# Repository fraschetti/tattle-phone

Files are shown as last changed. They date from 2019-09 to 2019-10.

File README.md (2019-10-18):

# Tattle Phone
A RaspberryPi enabled tattle phone capable of recording voice messages, converting them to text, & making everything available to you via [Slack](https://slack.com) or [Pipedream](https://pipedream.com). Originally inspired by this [No Fair! - This American Life](https://www.thisamericanlife.org/672/no-fair/prologue-2) segment.

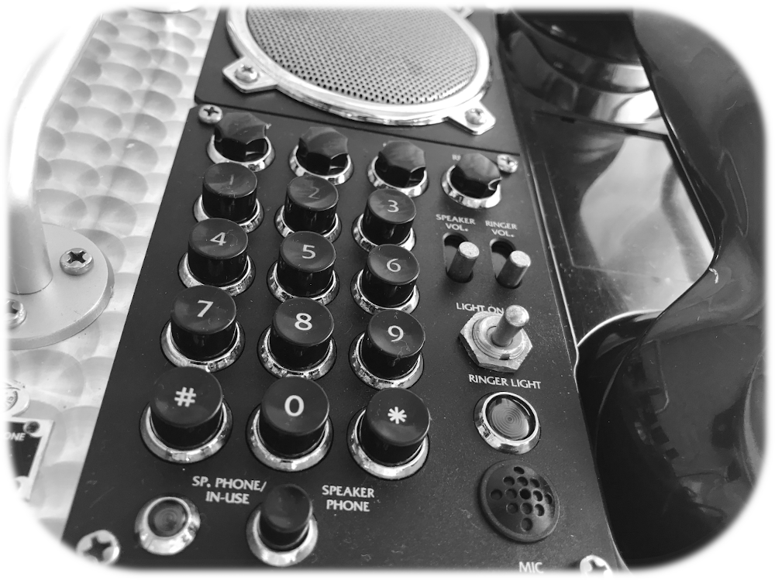
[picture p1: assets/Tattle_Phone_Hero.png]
Tattle phone


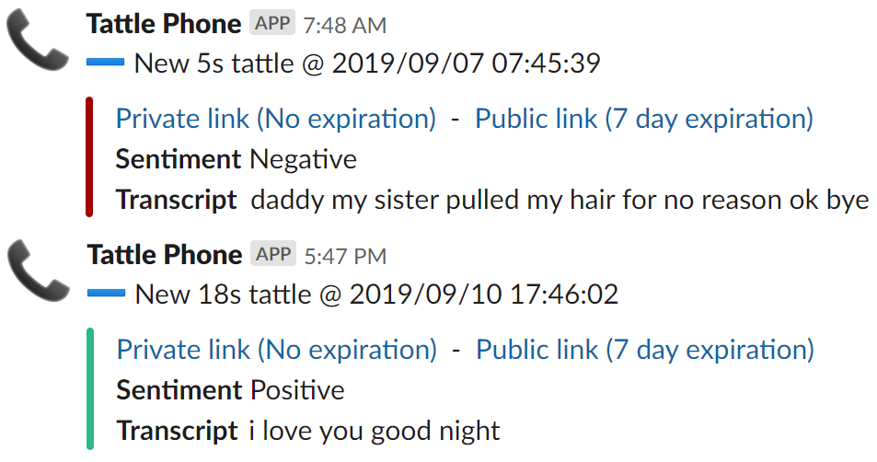
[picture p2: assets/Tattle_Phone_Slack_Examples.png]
Slack examples


**What's actually happens:**
- Picking up the telephone handset triggers the Python logic to start recording
- After the handset is placed back on the phone (or a maximum recording duration is reached), the recording is uploaded to Amazon S3
- The recording is then optionally passed through Amazon Transcribe (voice --> text) and Amazon Comprehend (text --> sentiment) for further analysis
  - NOTE: Both Transcribe and Comprehend have free usage plans that should be more than sufficient for this project
- After all processing is complete, a Slack or Pipedream message is posted with a link to the recording and transcript and sentiment information if enabled.

## BOM (Bill of Materials)
- Raspberry Pi Zero W or any other WiFi enabled Raspberry Pi
- Telephone with an analog receiver (two wires for the speaker & two wires for the microphone)
  - Telephones with the keypad in the handset are likely going to be a pain to use as the cord doesn't contain the microphone wires you'd want to leverage on the Pi you'll be mounting into the telephone base)
- Rasperry Pi compatible USB audio adapter
- [Optional] Status LED
- [Optional] 1k resistor for the status LED (only required if using a status LED)
- [Optional] PCB Screw Terminal Block (useful when prototyping)
- [Optional] 3.5mm 1/8 male headphone jack to terminal block adapter  (useful when prototyping)
- [Optional] Electret microphone (useful for prototyping)

#### Microphone protoype
- Search for "3.5mm audio terminal block" on eBay or AliExpress
- This prototype provided better quality recordings than my teleophone receiver implementation
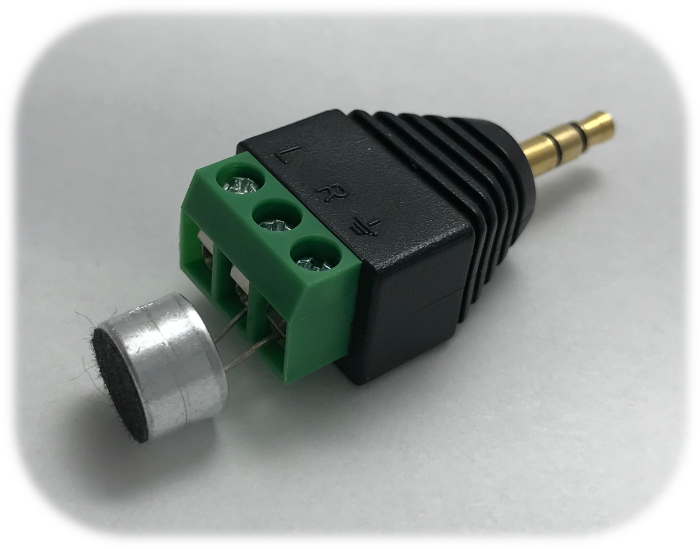
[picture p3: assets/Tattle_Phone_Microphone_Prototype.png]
Microphone prototype


#### USB audio adapter
- Search for "USB Sound Card Adapter" on eBay or AliExpress
- This model comes with a rather annoying red status LED which illuminates whenever the adapter is in use
  - It was literally a two minute task to slice open the case with a utility knife, desolder the surface mount LED, and put the case back together with a bit of cyanoacrylate ("super glue") 
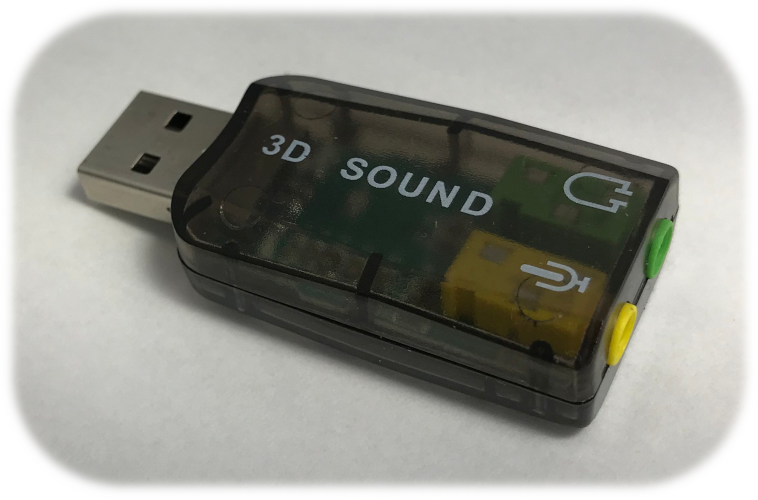
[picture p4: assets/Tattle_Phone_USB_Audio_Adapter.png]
USB Audio Adapter


#### PCB screw terminal block
- Search for "2.54mm PCB Screw Terminal Block" on eBay or AliExpress
- A six pole terminal block will satisfy the requirements of this project with room for future enhancements
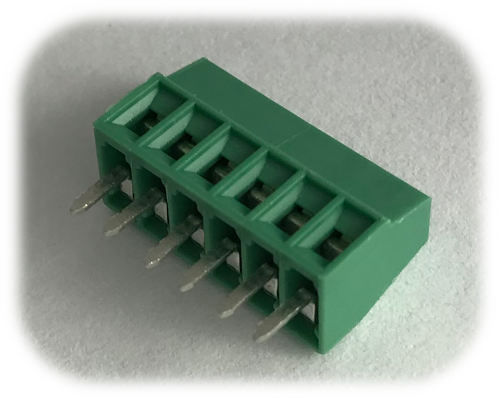
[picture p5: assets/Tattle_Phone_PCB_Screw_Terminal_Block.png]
PCB Screw Terminal Block


## Wiring diagram
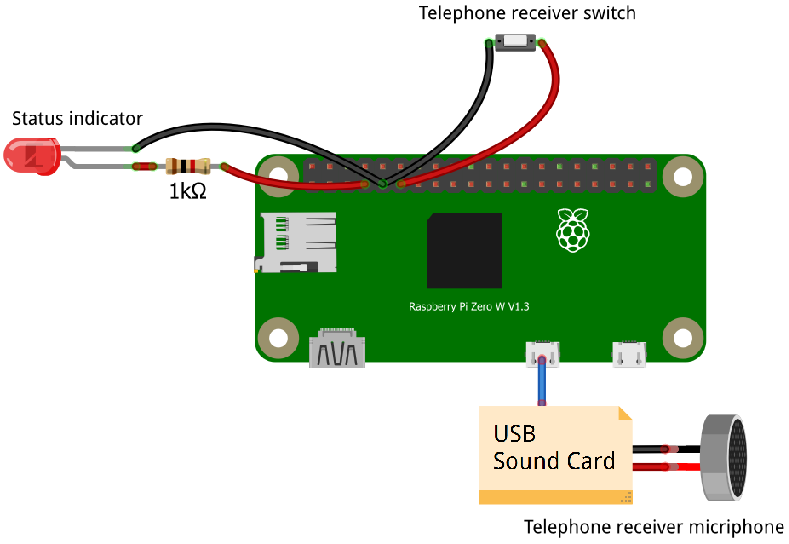
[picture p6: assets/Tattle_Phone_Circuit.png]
Wiring diagram


## Software
- Install the prequisites
  ```
  sudo apt-get install libportaudio0 libportaudio2 libportaudiocpp0 portaudio19-dev
  sudo python -m pip install pyaudio PyYAML boto3 slacker
  ```
- Populate your local yaml [configuration file](config.yaml)

- Populate your AWS credential and configuration files
  - /home/pi/.aws/credentials
    ```
    [default]
    aws_access_key_id = <aws_access_key_id>
    aws_secret_access_key = <aws_secret_access_key>
    ```  
  - /home/pi/.aws/config
    - Best practice would be to use the same region as your config.yaml file
    ```
    [default]
    region = <preferred_aws_region>
    ```
- Install the tattle-phone service - process adapted from [here](https://www.raspberrypi.org/forums/viewtopic.php?t=197513#p1247341)
  - Commands and scripts assume Pi is running [Raspian](https://www.raspberrypi.org/downloads/) and the tattle-phone project contents have been deployed at **/home/pi/tattle-phone**. To use a different path, simply modify the steps below, the [tattle.service](tattle.service) file and .sh files accordingly.
    ```
    sudo cp tattle.service /etc/systemd/system/tattle.service
    sudo chmod 644 /etc/systemd/system/tattle.service
    sudo systemctl daemon-reload
    sudo systemctl enable tattle.service
    sudo systemctl start tattle.service
    ```
## Power savings
Unfortunately none of the Raspberry Pi boards have any power saving modes and the best we can do is disable components we don't need. Assuming you're leveraging the on-board WiFI, you can still disable the Bluetooth hardware, HDMI output, and on-board status LEDs.

- A great resource for disabling the onboard WiFI and/or Bluetooth can be found [here](https://blog.sleeplessbeastie.eu/2018/12/31/how-to-disable-onboard-wifi-and-bluetooth-on-raspberry-pi-3/)
- To disable the on-board HDMI (and with a bit of work - the on-board LEDs), you might consider leveraging [tattle_power_savings.sh](tattle_power_savings.sh)
     - The command below assume the tattle-phone project have been deployed at **/home/pi/tattle-phone**
     ```
    sudo chmod 775 /home/pi/tattle-phone/tattle_power_savings.sh
    sudo sed -i -e '$i /home/pi/tattle-phone/tattle_power_savings.sh\n' /etc/rc.local
    ```
## My implementation
I was putting the finishing touches on the software when a last minute business trip popped up. I wanted to give my oldest daughter a fun way to contact me while I was away so I cobbled together a working tattle phone for her to use. It was a success!

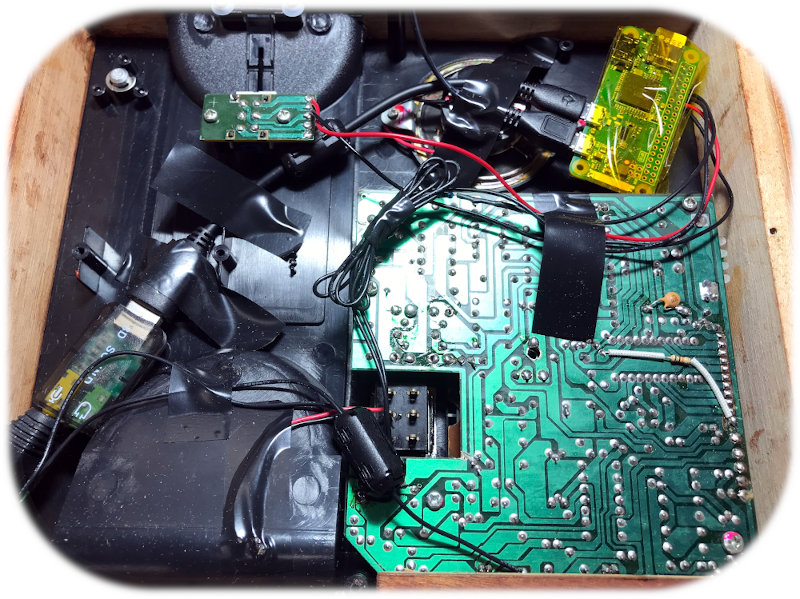
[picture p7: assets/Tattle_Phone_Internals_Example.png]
Internals Example

- It was fairly easy to use a multimeter to determine which wires I could leverage to detect the phone haved been lifted off the base. The other unncessary wires from the switch were trimmed to reduce clutter
- Luckily the phone's board was only a single layer and utilized through-hole components and that made quick work of leveraging the phone's existing components
  - It was easy enough to spot which pins were handling the microphone inputs and the existing on-board status LED for the phone.
  - I soldered in a handful of wires, cut the traces to isolate the microphone and LED from the rest of the board, and we were good to go.

## What would a v2 look like?
The Pi offers a lot of convienance but it is wildly overpowered for this project and even with the above *Power savings*, is going to waste a lot of energy * money. If I were to revisit this project, I'd likely start over using an ESP32 or similar microcontroller with built-in WiFi, processing power, and deep-sleep power saving modes (similar to what I used on my [ESP8266-TempSensor](https://github.com/fraschetti/ESP8266-TempSensor) project).

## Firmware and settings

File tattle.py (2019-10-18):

#!/usr/bin/python

import os
import sys
import logging
import logging.handlers as handlers
import yaml
import json
import RPi.GPIO as GPIO
import pyaudio
import time
import threading
import boto3
import botocore
import requests
from sound_recorder import SoundRecorder
from datetime import datetime
from tempfile import mkstemp
from slacker import IncomingWebhook


file_log_format = '%(asctime)s  %(levelname)s  %(message)s'
console_log_format = file_log_format

logger = logging.getLogger()
logger.setLevel(logging.INFO)

file_handler = handlers.TimedRotatingFileHandler('tattle.log', when='midnight')
file_handler.setFormatter(logging.Formatter(file_log_format))
logger.addHandler(file_handler)

console_handler = logging.StreamHandler()
console_handler.setFormatter(logging.Formatter(console_log_format))
logger.addHandler(console_handler)

cfg = None
handset_pin = None
led_pin = None
need_receiver_reset = False #Requires the reciver to be 'hung up' before the next recording

run_test = False #Run once and exit

def main():
        global cfg
        global handset_pin
        global led_pin
        global need_receiver_reset 

	p = pyaudio.PyAudio()
	device_count = p.get_device_count()
	
	logger.info("")
	logger.info("")
	logger.info("-=Tattle App=-")
	logger.info("")
	logger.info("Loading config...")

        led_pin = None

        try:
            with open("config.yaml", 'r') as ymlfile:
                cfg = yaml.load(ymlfile, Loader=yaml.FullLoader)
                logger.info("\n\n" + yaml.dump(cfg, Dumper=yaml.Dumper))

                handset_pin = cfg["handset"]["handset_pin"]
                led_pin = cfg["recording"]["led_pin"]

                if not handset_pin:
                    logger.error("Handset pin not configured")
                    return
        except Exception:
            logger.exception("Config read error")
            return

	logger.info("- Audio devices (" + str(device_count) + ") -")
	for i in range(device_count):
	    device_info = p.get_device_info_by_index(i)
	    print_device_info(device_info)	
		
	logger.info("")
	logger.info("- Default recording device -")
	mic_device_info = p.get_default_input_device_info()
	print_device_info(mic_device_info)

        # Pin Setup:
        GPIO.setwarnings(False)
        GPIO.setmode(GPIO.BCM) # Broadcom pin-numbering scheme
        GPIO.setup(handset_pin, GPIO.IN, pull_up_down=GPIO.PUD_UP) # Button pin set as input w/ pull-up

        if led_pin:
            GPIO.setup(led_pin, GPIO.OUT) # LED pin set as output
            GPIO.output(led_pin, GPIO.LOW)

        logged_waiting_msg = False

        if is_phone_off_hook():
            logger.warn("Receiver initial state is off the hook. Preventing false recording on start")
            need_receiver_reset = True

        while True:
            try:
                if not logged_waiting_msg:
	            logger.info("")
	            logger.info("-------------------------------------")
	            logger.info("Waiting for tattle...")
	            logger.info("-------------------------------------")
	            logger.info("")
                    logged_waiting_msg = True

                if is_phone_off_hook() or run_test:
                    #Need to wait until the reciver is hung up again before a new recording can occur
                    if not need_receiver_reset:
                        logged_waiting_msg = False
                        capture_audio()

                    if run_test:
                        need_receiver_reset = True #Prevent multiple recording during the test cycle
                else:
                    need_receiver_reset = False
            except Exception:
                logger.exception("Main loop error")

            time.sleep(0.5)


def is_phone_off_hook():
    return GPIO.input(handset_pin)


##TODO CHRIS Encode to MP3 if it makes sense (currently doesn't)
##TODO CHRIS move from path aws credentials to yaml settings
##TODO CHRIS flash LED on startup
##TODO CHRIS send slack msssage on service start/stop ?
##RODO CHRIS send initial slack msg immediately and updates as post-processing occurs
##TODO CHRIS https://www.instructables.com/id/Disable-the-Built-in-Sound-Card-of-Raspberry-Pi/
##TODO CHRIS https://aws.amazon.com/blogs/database/indexing-metadata-in-amazon-elasticsearch-service-using-aws-lambda-and-python/
##TODO CHRIS Doc disabling built-in audio - https://www.raspberrypi.org/forums/viewtopic.php?t=37873
def capture_audio():
    rec_tmp_file_path = None

    try:
        global need_receiver_reset 

        base_name = "tattle_" + time.strftime('%Y%m%d_%H%M%S')

        #recording 
        rec_filename = base_name + ".wav"
        rec_tmp_fd, rec_tmp_file_path = mkstemp()
        os.close(rec_tmp_fd)

        tattle_props = {
                'id' : base_name,
                'rec_filename' : rec_filename,
                'timestamp' : datetime.now().strftime("%Y/%m/%d %H:%M:%S"),
                'rec_url' : None,
                'rec_public_url' : None,
                'rec_duration' : None,
                'transcript_url' : None,
                'transcript' : None,
                'sentiment' : None,
                'key_phrases' : [],
            }

        with SoundRecorder(rec_tmp_file_path) as rec:
    	    logger.info("Starting recording - " + rec_filename)
    	    rec.start_recording()
            adjust_recording_led(True)

            recording_min_secs = int(cfg["recording"]["min_secs"])
            recording_max_secs = int(cfg["recording"]["max_secs"])

            min_record_end = None
            max_record_end = None

            if recording_min_secs and recording_min_secs > 0:
                min_record_end = time.time() + recording_min_secs
            if recording_max_secs and recording_max_secs > 0:
                max_record_end = time.time() + recording_max_secs

            continue_recording = True

            while continue_recording:
    	        time.sleep(0.25)

                min_met = min_record_end == None or time.time() >= min_record_end
                max_met = not max_record_end == None and time.time() >= max_record_end
            
                if not is_phone_off_hook():
                    continue_recording = False

                #Force the recording to go the min duration
                if not min_met:
                    continue_recording = True

                #Abort the recording if it exceeded the max duration
                if max_met:
    	            logger.info("Aborting recording due to max duration (" + str(recording_max_secs) + ")")
                    continue_recording = False
                    need_receiver_reset = True

    	    logger.info("Stopping recording")
    	    rec.stop_recording()
            adjust_recording_led(False)
            duration = rec.get_duration()
            tattle_props["rec_duration"] = duration
            logger.info("Recording finished - Duration: " +  str(round(duration, 2)))

            t = threading.Thread(
                target=post_capture_processing,
                args=(tattle_props, base_name, rec_filename, rec_tmp_file_path),
            )
            t.setDaemon(True)
            t.start()
    except Exception:
        logger.exception("Capture audio exception")
    
def print_device_info(device_info):
	logger.info("Index: " + str(device_info.get('index')) + ", Name: " + device_info.get('name'))

def adjust_recording_led(enabled):
    if enabled:
        GPIO.output(led_pin, GPIO.HIGH)
    else:
        GPIO.output(led_pin, GPIO.LOW)

def post_capture_processing(tattle_props, base_name, rec_filename, rec_tmp_file_path):
    props_tmp_file_path = None
    transcript_tmp_file_path = None
    
    try:
    	logger.info("Starting post-recording work...")

        #recording properties
        props_filename = base_name + ".json"
        props_tmp_fd, props_tmp_file_path = mkstemp()
        os.close(props_tmp_fd)

        #transcript
        transcript_filename = base_name + "_trascription"
        transcript_tmp_fd, transcript_tmp_file_path = mkstemp()
        os.close(transcript_tmp_fd)

        aws_config = cfg["aws"]
        aws_comprehend_region = aws_config["comprehend_region"]
        s3_bucket = aws_config["s3_bucket"]

        logger.info("Uploading recording to S3: " + rec_filename)
        s3_url = upload_to_s3(rec_filename, rec_tmp_file_path, s3_bucket)
        if s3_url:
            tattle_props['rec_url'] = s3_url

            s3_public_url = get_s3_presigned_url(rec_filename, s3_bucket)
            if s3_public_url:
                tattle_props['rec_public_url'] = s3_public_url

            upload_props_to_s3(tattle_props, props_filename, props_tmp_file_path, s3_bucket)

            if cfg["text_analysis"]["transcription"]:
                transcription = transcribe_recording(transcript_filename, transcript_tmp_file_path, s3_url, s3_bucket, tattle_props)

                if transcription and len(transcription) > 0:
                    upload_props_to_s3(tattle_props, props_filename, props_tmp_file_path, s3_bucket)

                if analyze_text(tattle_props, transcription, aws_comprehend_region):
                    upload_props_to_s3(tattle_props, props_filename, props_tmp_file_path, s3_bucket)

            send_slack_msg(tattle_props)

    	logger.info("Finished post-recording work")
        logger.info("Final summary JSON document: \n" + json.dumps(tattle_props, sort_keys=True, indent=4))
    except Exception:
        logger.exception("Post-processing exception")
    finally:
        if rec_tmp_file_path:
            os.remove(rec_tmp_file_path)
        if props_tmp_file_path:
            os.remove(props_tmp_file_path)
        if transcript_tmp_file_path:
            os.remove(transcript_tmp_file_path)

        if run_test: #Quit after test
            sys.exit(0)

def upload_props_to_s3(tattle_props, props_filename, props_tmp_file_path, s3_bucket):
    with open(props_tmp_file_path, 'w') as out_file:
        out_file.write(json.dumps(tattle_props, sort_keys=True, indent=4))

    logger.info("Uploading tattle summary JSON document to S3: " + props_filename)

    upload_to_s3(props_filename, props_tmp_file_path, s3_bucket)

def upload_to_s3(upload_filename, local_file_path, s3_bucket):
    try:
        logger.info("Uploading file to S3")

        s3_upload_start = time.time()

        s3_client = boto3.client('s3')
        s3UploadRsp = s3_client.upload_file(local_file_path, s3_bucket, upload_filename)
        ##s3UploadRsp = s3_client.upload_file(local_file_path, s3_bucket, upload_filename, ExtraArgs={'ACL': 'public-read'})

        logger.info("S3 upload response: " + str(s3UploadRsp))
        s3_upload_elapsed = time.time() - s3_upload_start
        logger.info("Uploaded file to S3 in "
            + str(round(s3_upload_elapsed, 2))
            + " seconds"
        )

        s3_url = "https://" + s3_bucket + ".s3.amazonaws.com/" + upload_filename

        logger.info("S3 URL: " + s3_url)
        return s3_url
    except botocore.exceptions.ClientError as ce:
        logger.exception("AWS S3 upload error (ClientError)")
    except Exception:
        logger.exception("AWS S3 upload error (Generic)")

def get_s3_presigned_url(filename, s3_bucket):
    try:
        logger.info("Fetching S3 presigned URL for: " + filename)

        s3_start = time.time()

        s3_client = boto3.client('s3')
        s3PresignedUrlRsp = s3_client.generate_presigned_url('get_object', Params={'Bucket': s3_bucket, 'Key': filename}, ExpiresIn=604800)

        logger.info("S3 presigned URL response: " + str(s3PresignedUrlRsp))
        s3_elapsed = time.time() - s3_start
        logger.info("S3 presigned URL retrieved in "
            + str(round(s3_elapsed, 2))
            + " seconds"
        )

        return s3PresignedUrlRsp
    except botocore.exceptions.ClientError as ce:
        logger.exception("AWS S3 upload error (ClientError)")
    except Exception:
        logger.exception("AWS S3 upload error (Generic)")

def transcribe_recording(transcript_name, transcript_file_path, s3_url, s3_bucket, tattle_props):
    try:
        logger.info("Starting transcribe job - " + s3_url)

        s3_transcribe_start = time.time()

        transcribe = boto3.client('transcribe')
        job_name = transcript_name
        job_uri = s3_url
        transcribe.start_transcription_job(
            TranscriptionJobName=job_name,
            Media={'MediaFileUri': job_uri},
            MediaFormat='wav',
            LanguageCode='en-US',
            OutputBucketName=s3_bucket
        )

        while True:
            status = transcribe.get_transcription_job(TranscriptionJobName=job_name)
            if status['TranscriptionJob']['TranscriptionJobStatus'] in ['COMPLETED', 'FAILED']:
                break
            time.sleep(5)
        logger.info("Transcript results:\n" + str(status))

        s3_transcribe_elapsed = time.time() - s3_transcribe_start
        logger.info("Transcribed recording in "
            + str(round(s3_transcribe_elapsed, 2))
            + " seconds"
        )

        if status['TranscriptionJob']['TranscriptionJobStatus'] == "COMPLETED":
            transcript_url = status['TranscriptionJob']['Transcript']['TranscriptFileUri']
            tattle_props['transcript_url'] = transcript_url

            s3_transcript_filename = transcript_url[transcript_url.rfind("/") + 1 :]

            logger.info("Downloading transcript: " + transcript_url)
            s3_client = boto3.client('s3')

            s3_download_start = time.time()
            s3DownloadRsp = s3_client.download_file(s3_bucket, s3_transcript_filename, transcript_file_path)

            logger.info("S3 download response: " + str(s3DownloadRsp))
            s3_download_elapsed = time.time() - s3_download_start
            logger.info("Downloaded file from S3 in "
                + str(round(s3_download_elapsed, 2))
                + " seconds"
            )

            with open(transcript_file_path, 'r') as f:
                transcript_content = json.load(f)
                transcripts = transcript_content["results"]["transcripts"]
                transcript = transcripts[0]["transcript"]
                logger.info("Transcript: " + str(transcript))

                tattle_props["transcript"] = transcript

            return transcript
    except botocore.exceptions.ClientError:
        logger.exception("AWS transcribe upload error (ClientError)")
    except Exception:
        logger.exception("AWS transcribe error (Generic)")

    return None

def analyze_text(tattle_props, transcript, aws_comprehend_region):
    if not transcript:
        return False
        
    transcript = transcript.strip()
        
    if len(transcript) == 0:
        return False

    if aws_comprehend_region == None or len(aws_comprehend_region.strip()) == 0:
        logger.info("Skipping sentiment analysis as no AWS region has been configured")
        return False

    logger.info("Starting text analysis...")
    updated_props = False

    comprehend = boto3.client(service_name='comprehend', region_name=aws_comprehend_region)

    ##Sentiment analysis
    if cfg["text_analysis"]["sentiment"]:
        s3_analysis_start = time.time()

        sentiment_rsp = comprehend.detect_sentiment(Text=transcript, LanguageCode='en')

        s3_analysis_elapsed = time.time() - s3_analysis_start
        logger.info("Sentiment analysis completed in "
            + str(round(s3_analysis_elapsed, 2))
            + " seconds"
        )

        logger.info("Sentiment response:\n" + str(sentiment_rsp))

        if sentiment_rsp["ResponseMetadata"]["HTTPStatusCode"] == 200:
            tattle_props['sentiment'] = sentiment_rsp['Sentiment']
            updated_props = True

    ##Key phrase analysis
    if cfg["text_analysis"]["key_phrases"]:
        s3_analysis_start = time.time()

        key_phrases_rsp = comprehend.detect_key_phrases(Text=transcript, LanguageCode='en')

        s3_analysis_elapsed = time.time() - s3_analysis_start
        logger.info("Key phrase analysis completed in "
            + str(round(s3_analysis_elapsed, 2))
            + " seconds"
        )

        logger.info("Key phrases response:\n" + str(key_phrases_rsp))

        if key_phrases_rsp["ResponseMetadata"]["HTTPStatusCode"] == 200 and 'KeyPhrases' in key_phrases_rsp:
            for phrase_obj in key_phrases_rsp['KeyPhrases']:
                phrase = phrase_obj['Text']
                if phrase and len(phrase) > 0 and not phrase in tattle_props['key_phrases']:
                    tattle_props['key_phrases'].append(phrase)
                    updated_props = True

    return updated_props

def send_slack_msg(tattle_props):
    slack_cfg = cfg["slack"]
    slack_webhook_url = slack_cfg["webhook_url"]
    slack_channel = slack_cfg["channel"]
    slack_username = slack_cfg["username"]
    slack_icon_url = slack_cfg["icon_url"]
    slack_icon_emoji = slack_cfg["icon_emoji"]

    pipedream_cfg = cfg["pipedream"]
    pipedream_webhook_url = pipedream_cfg["webhook_url"]

    tattle_id = tattle_props["id"]
    tattle_timestamp = tattle_props["timestamp"]
    tattle_recording_url = tattle_props["rec_url"]
    tattle_recording_public_url = tattle_props["rec_public_url"]
    tattle_recording_duration = tattle_props["rec_duration"]
    tattle_transcript = tattle_props["transcript"]
    tattle_sentiment = tattle_props["sentiment"]
    tattle_key_phrases = tattle_props["key_phrases"]

    pipedream_msg = {}

    #good, warning, danger
    color = "good"
    if tattle_sentiment:
        if tattle_sentiment == "MIXED":
            tattle_sentiment = "Mixed"
            color = "warning"
        elif tattle_sentiment == "POSITIVE":
            tattle_sentiment = "Positive"
            color = "good"
        elif tattle_sentiment == "NEUTRAL":
            tattle_sentiment = "Neutral"
            color = "good"
        elif tattle_sentiment == "NEGATIVE":
            tattle_sentiment = "Negative"
            color = "danger"

    attachments = [{}]
    attachment = attachments[0]

    attachment["mrkdwn_in"] = ["text", "pretext"]
    attachment["pretext"] = ":heavy_minus_sign: New " + str(int(round(tattle_recording_duration))) + "s tattle @ " + tattle_timestamp
    attachment["fallback"] = attachment["pretext"]
    attachment["color"] = color

    pipedream_msg["timestamp"] = tattle_timestamp
    pipedream_msg["duration"] = round(tattle_recording_duration, 2)
    pipedream_msg["tattle_url_private"] = tattle_recording_url
    pipedream_msg["tattle_url_public"] = tattle_recording_public_url

    text_arr = []

    url_link = "<" + tattle_recording_url + "|Private link (No expiration)>"
    if tattle_recording_public_url and len(tattle_recording_public_url) > 0:
        url_link = url_link + "  -  " + "<" + tattle_recording_public_url + "|Public link (7 day expiration)>"
    text_arr.append(url_link)

    if tattle_sentiment and len(tattle_sentiment) > 0:
        text_arr.append("*Sentiment* " + tattle_sentiment)
        pipedream_msg["sentiment"] = tattle_sentiment

    if tattle_key_phrases and len(tattle_key_phrases) > 0:
        text_arr.append("*Key Phrases* " + ", ".join(tattle_key_phrases))
        pipedream_msg["key_phrases"] = tattle_key_phrases

    if tattle_transcript and len(tattle_transcript) > 0:
        if len(tattle_transcript) > 2000:
            tattle_transcript = tattle_transcript[0:2000]
        text_arr.append("*Transcript* " + tattle_transcript)
        pipedream_msg["transcript"] = tattle_transcript

    if not text_arr == None and len(text_arr) > 0:
        text = "\n".join(text_arr)

    attachment["text"] = text
    #attachment["footer"] = "My footer"

    attachments_json = json.dumps(attachments, sort_keys=True, indent=4)

    slack_msg = {}

    if not slack_channel == None and len(slack_channel) > 0:
        slack_msg["channel"] = slack_channel
    if not slack_icon_url == None and len(slack_icon_url) > 0:
        slack_msg["icon_url"] = slack_icon_url
    if not slack_icon_emoji == None and len(slack_icon_emoji) > 0:
        slack_msg["icon_emoji"] = slack_icon_emoji
    if not slack_username == None and len(slack_username) > 0:
        slack_msg["username"] = slack_username

    slack_msg["attachments"] = attachments

    try:
        logger.info("Slack WebHook postMessage json:\n" + json.dumps(slack_msg, sort_keys=True, indent=4))

        webHook = IncomingWebhook(slack_webhook_url)
        webHookRsp = webHook.post(slack_msg)
        logger.info("Slack WebHook postMessage response: " + webHookRsp.text)

        if not webHookRsp.ok:
            logger.error("Slack WebHook message send failed: " + webHookRsp.text)
    except Exception as e:
        logger.exception("Slack WebHook message send error: " + str(e))

    try:
        logger.info("Pipedream WebHook post json:\n" + json.dumps(pipedream_msg, sort_keys=True, indent=4))

        webHookRsp= requests.post(pipedream_webhook_url, data=json.dumps(pipedream_msg),
            headers={'Content-Type': 'application/json'}
        )
        logger.info("Pipedream WebHook post response: " + webHookRsp.text)

        if not webHookRsp.ok:
            logger.error("Pipedream WebHook message send failed: " + webHookRsp.text)
    except Exception as e:
        logger.exception("Pipedream WebHook message send error: " + str(e))

if __name__ == '__main__':
    try:
	main()
    except KeyboardInterrupt, e:
        logging.info("Stopping...")
    finally:
        GPIO.cleanup() # cleanup all GPIO

    logging.info("Stopped")

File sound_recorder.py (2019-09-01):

# -*- coding: utf-8 -*-

import pyaudio
import wave
import time

## Adapted from sloria's recorder.py - https://gist.github.com/sloria/5693955
## License - MIT - https://sloria.mit-license.org/

# The MIT License (MIT)
# Copyright © 2019 Steven Loria
#
# Permission is hereby granted, free of charge, to any person obtaining a copy of this software and associated documentation files (the “Software”), to deal in the Software without restriction, including without limitation the rights to use, copy, modify, merge, publish, distribute, sublicense, and/or sell copies of the Software, and to permit persons to whom the Software is furnished to do so, subject to the following conditions:
#
# The above copyright notice and this permission notice shall be included in all copies or substantial portions of the Software.
#
# THE SOFTWARE IS PROVIDED “AS IS”, WITHOUT WARRANTY OF ANY KIND, EXPRESS OR IMPLIED, INCLUDING BUT NOT LIMITED TO THE WARRANTIES OF MERCHANTABILITY, FITNESS FOR A PARTICULAR PURPOSE AND NONINFRINGEMENT. IN NO EVENT SHALL THE AUTHORS OR COPYRIGHT HOLDERS BE LIABLE FOR ANY CLAIM, DAMAGES OR OTHER LIABILITY, WHETHER IN AN ACTION OF CONTRACT, TORT OR OTHERWISE, ARISING FROM, OUT OF OR IN CONNECTION WITH THE SOFTWARE OR THE USE OR OTHER DEALINGS IN THE SOFTWARE.

class SoundRecorder:
    def __init__(self, filename):
        self._pa = pyaudio.PyAudio()
        self.channels = 1
        self.rate = 44100
        self.frames_per_buffer = 256
        self.wavefile = self._prepare_file(filename)
 
        self._stream = None
        self._start_time = None
        self._duration = None

    def __enter__(self):
        return self

    def __exit__(self, exception, value, traceback):
        self.close()

    def start_recording(self):
        self._stream = self._pa.open(format=pyaudio.paInt16,
                                        channels=self.channels,
                                        rate=self.rate,
                                        input=True,
                                        frames_per_buffer=self.frames_per_buffer,
                                        stream_callback=self.get_callback())
        self._start_time = time.time()
        self._stream.start_stream()
        return self

    def stop_recording(self):
        self._stream.stop_stream()
        if self._start_time:
            self._duration = time.time() - self._start_time
        return self

    def get_duration(self):
        if not self._duration == None:
            return self._duration

        if self._stream == None or self._start_time == None:
            return None

        #Return current time delta if still recording
        return time.time() - self._start_time

    def get_callback(self):
        def callback(in_data, frame_count, time_info, status):
            self.wavefile.writeframes(in_data)
            return in_data, pyaudio.paContinue
        return callback
		
    def _prepare_file(self, fname, mode='wb'):
        wavefile = wave.open(fname, mode)
        wavefile.setnchannels(1)
        wavefile.setsampwidth(self._pa.get_sample_size(pyaudio.paInt16))
        wavefile.setframerate(self.rate)
        return wavefile

    def close(self):
        self._stream.close()
        self._stream = None
        self._pa.terminate()
        self._pa = None
        self.wavefile.close()
        self.wavefile = None

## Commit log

2019-09-06 Adding initial receiver state detection logic. Swapping receiver check logic for production state
    [tattle.py]
2019-09-07 Fixing the good Slack color string
    [tattle.py]
2019-09-15 Adding wiring diagrams
    [Tattle_Phone_Circuit.fzz]
2019-09-15 Removing broadcom pin numbering comment
2019-10-02 Updating BOM
2019-10-09 Progress on the power savingss notes
2019-10-13 Additional power savings documentation work
2019-10-13 Adding base power savings shell script
